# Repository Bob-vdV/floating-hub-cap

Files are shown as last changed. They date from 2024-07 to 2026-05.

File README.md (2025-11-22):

# Floating-hub-cap

Openscad files for a floating wheel hub cap. More details are at https://www.printables.com/model/928406. 

The latest STL files are downloadable at https://github.com/Bob-vdV/floating-hub-cap/releases/latest.

## Online Customizer (new!)
Check out the online customizer at https://bobvdv.nl/floating-hub-cap. 
To use it, click on 'Customize' and then change the main parameters for your hub cap size. Then click 'Render' and 'Download STL' for each part in the `selected_part` dropdown menu. 

## Manual generation

Each STL file can be generated normally using the openscad GUI. The nightly version of openscad is highly recommended because of its better performance with manifold. All parameters can be changed using the customizer in `centercap_main.scad`. The most important four parameters are at the top under `main parameters`. For each part in the `selected part` dropdown menu, render and export it to an STL.

## Customizing and generating STL files automatically

To generate the STL files automatically you also need python installed. 

The parameters of the hub cap can be set in `centercap_main.json`. Any parameter listed in `centercap_main.scad` can be added and changed via the json file. 

All STL files can then be generated by executing the following command:

`python ./make.py` 

This python script creates the build folder and then generates all STL files for all parameter sets in the json file.

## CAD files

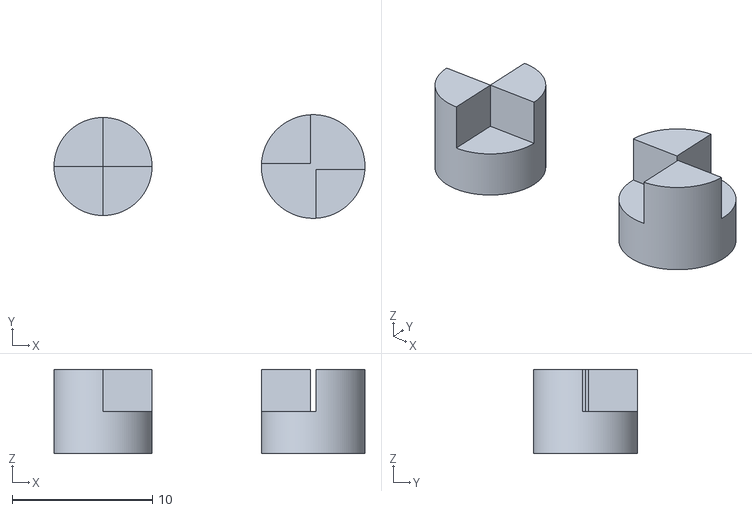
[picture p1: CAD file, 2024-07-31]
opposite_lock.stl
22.2 x 7.40 x 6.00

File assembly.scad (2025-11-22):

./centercap/assembly.scad

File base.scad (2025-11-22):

./centercap/base.scad

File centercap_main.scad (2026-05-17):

include <centercap/assembly.scad>
include <centercap/base.scad>
include <centercap/swing_screws.scad>
include <centercap/top_plain.scad>
include <centercap/top_curved.scad>
include <centercap/top_vw_curved.scad>
include <centercap/top_vw_flat.scad>

$fn = $preview ? 16 : 128;

/* [Main parameters] */
selected_part = "base"; // ["assembly", "base", "swing", "top-plain", "top-curved", "top-vw-curved", "top-vw-flat"]
outer_diam = 65; // [50:0.1:120]
inner_ring_diam = 56; // [50:0.1:120]
clip_straight_height = 4.5; // Height of the inner ring

/* [General parameters] */
tiny = 0.01;
layer_height = 0.2;

/* [Bearing parameters] */
bearing_outer_diam = 22;
bearing_inner_diam = 8;
bearing_height = 7;
bearing_tolerance= 0.0;

bearing_ring_diam = 12.0 - 0.5;

/* [Base parameters] */
base_height = 2;

bearing_wall_width = 1.6;
base_hole_clearance = 0.8;
bearing_lip_width = 0.75;
bearing_lip_height = 0.5;

inner_ring_height = 10;
inner_ring_wall_width = 2;

number_of_clips = 6;
clip_clearance = 2;
clip_length = 8;
clip_width = 1.8;
clip_slant_height = 5;
clip_end_width = 1.6;
clip_height = clip_straight_height + clip_end_width + clip_slant_height;

/* [Top parameters] */
endcap_tolerance = 0.2;
endcap_outer_tolerance = 0.4;
endcap_height = 1;
endcap_base_clearance = 2.0;

bottom_height = 2;

mid_diam = bearing_ring_diam;
mid_height = endcap_base_clearance + base_height + bearing_lip_height;

top_diam = bearing_inner_diam;
top_height = 5.0;

endcap_hole_height = bottom_height + mid_height + top_height - endcap_height;
endcap_outer_diam = outer_diam - endcap_outer_tolerance;

top_nut_tol = 0.8;
top_nut_lowerer = 0.2;

/* [Swing parameters] */
arm_width = 13.5;
arm_clearance = 3.5;
arm_length = inner_ring_diam / 2 - inner_ring_wall_width - arm_clearance;
arm_height = 3;

bearing_start_z_offset = 1.6;
bearing_z_start = arm_height + bearing_start_z_offset;
bearing_z_mid = bearing_z_start + bearing_height / 2;

nuts_per_side = 2;
nut_width = 8.08; // Measured corner to corner
nut_height = 3.2;
nut_hole_size = 4.2;
nut_tolerance = 0.2;
nut_loose_width = nut_width + nut_tolerance;
nut_clearance = 0.2; // Wall thickness
screw_head_height = 2 * 3.2;

swing_clearance = 1;
swing_height = bearing_height + arm_height + bearing_start_z_offset - swing_clearance - screw_head_height;

shaft_height = bearing_height - top_height;
shaft_upper_diam = bearing_inner_diam - bearing_tolerance;

swing_inner_radius = arm_length - nut_loose_width - 2 * nut_clearance;

/* [Key parameters] */
key_size = 3.0;
m3_hole_diam = 3.5;//3.0
m3_head_diam = 6.35;
m3_loose_diam = m3_head_diam + nut_tolerance;
m3_head_height = 2.0;
m3_loose_hole_diam = m3_hole_diam;// + 0.5;
m3_hole_depth = 7.5;
m3_roof_thickness = 4.0; //2.5
m3_nut_diam = m3_loose_diam;
m3_nut_height = 2.15;
key_width = 2.1;

echo("Max screw length:", m3_roof_thickness + bearing_height + mid_height);

/* [Curved VW parameters] */
logo_height = 1;
dome_height = 4;

// ------ CODE ------
if (selected_part == "assembly") {
  assemblyCut();
} else if (selected_part == "base") {
  centercap_base();
} else if (selected_part == "swing") {
  centercap_swing_screws();
} else if (selected_part == "top-plain") {
  CenterCapTopPlain();
} else if (selected_part == "top-curved") {
  CenterCapTopCurved();
} else if (selected_part == "top-vw-curved") {
  centercap_top_vw_curved();
} else if (selected_part == "top-vw-flat") {
  centercap_top_vw_flat();
} else {
  echo("Unknown part selected");
}

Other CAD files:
fast_dome.scad
centercap/assembly.scad
centercap/base.scad
centercap/centercap_top_vw_curved.scad
centercap/centercap_top_vw_flat.scad
centercap/fast_dome.scad
centercap/hubcap_tester.scad
centercap/key.scad
centercap/ribbed_hole.scad
centercap/swing_screws.scad
centercap/top_curved.scad
centercap/top_plain.scad
centercap/top_vw_curved.scad
centercap/top_vw_flat.scad
centercap/vw.scad
hubcap_tester.scad
key.scad
ribbed_hole.scad
swing_screws.scad
test/bearing_tester.scad
top_plain.scad
top_vw_curved.scad
top_vw_flat.scad
vw.scad

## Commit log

2024-08-05 add python generation script
    [centercap_base_65mm.stl, centercap_base_75mm.stl, centercap_swing_screws_65mm.stl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]
2024-08-05 add Qt to gh action
    [centercap_base_65mm.stl, centercap_base_75mm.stl, centercap_swing_screws_65mm.stl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]
2024-08-05 cleanup, update readme
    [centercap_params.scad, centercap_swing.scad, centercap_swing_sand.scad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]
2024-10-21 add 60mm version
2024-10-22 add assembly scad, general cleanup
    [centercap_assembly.scad, centercap_base.scad, centercap_params.scad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]
2024-10-22 add 55mm, enable manifold
    [centercap_swing_screws.scad]
2024-11-05 Added variable for number of clips (defaults to 4)
    [centercap_base.scad, centercap_params.scad]
2024-11-05 Fix bug for clip clearances with odd number of clips
    [centercap_base.scad]
2024-11-12 decrease clip thickness
    [centercap_params.scad]
2024-11-22 Change vw logo, add clearances to top for wheel
    [centercap_params.scad, centercap_top_plain.scad, centercap_top_vw_curved.scad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]
2024-11-23 Add bump to swing for locking bearing in place
    [centercap_params.scad, centercap_swing_screws.scad]
2024-11-24 add 100mm version
2024-11-24 Simplify bearing bump for swing
    [centercap_params.scad, centercap_swing_screws.scad]
2025-03-06 Replace swing connector with PrintABlok
    [000a_ConnectorNeg_Flat.stl, centercap_assembly.scad, centercap_params.scad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]
2025-03-06 remove old folder
    [centercap_swing.scad, centercap_swing.stl, centercap_swing_sand.scad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]
2025-03-08 add outer clearance to swing
    [centercap_params.scad]
2025-03-13 v2 version: added screw to top cap, fixed clips, fixed swing clearance issues
    [000a_ConnectorNeg_Flat.stl, centercap_assembly.scad, centercap_base.scad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]
2025-03-13 add bearing tester file
    [bearing_tester.scad]
2025-04-02 add 64mm version for Saturn, Vauxhall, Opel
2025-04-13 decrease clip width and head size for better flexibility
    [centercap_base.scad, centercap_params.scad]
2025-05-16 make m3 hole ribbed for strength + small tweaks
    [centercap_assembly.scad, centercap_params.scad, centercap_top_plain.scad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]
2025-08-03 adjust 65mm vw parameters
2025-08-07 adjust 65mm, 68mm parameters
    [centercap_params.scad]
2025-08-09 (untested) attempt at more rigid connection using wood screw
    [centercap_assembly.scad, centercap_base.scad, centercap_params.scad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]
2025-08-13 v3 final (copy) (edit)
    [centercap_assembly.scad, centercap_params.scad, centercap_swing_screws.scad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]
2025-09-06 Simplify customizer usage
    [centercap_assembly.scad, centercap_base.scad, centercap_main.scad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]
2025-11-16 add gh pages integration
    [centercap_assembly.scad, centercap_base.scad, centercap_main.scad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]
2025-11-22 add symlinks for gh pages
    [assembly.scad, base.scad, centercap_main.scad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]
2026-05-17 Add curved top without logo
    [centercap_main.scad, key.scad, top_curved.scad]
2026-10-03 Update bmw cap to follow 68mm spec
